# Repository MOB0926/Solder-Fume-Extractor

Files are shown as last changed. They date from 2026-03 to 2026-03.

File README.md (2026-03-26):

# Solder-Fume-Extractor

# Why?

- I made this project because I needed a fan extarctor in general and thought it would be fun to just make one as a project for Blueprint, in my effrot to gain experience in engeneering and design.

# What?

- This project is my attempt at making a custom fume extractor using a 120mm pc fan and a custom PCB.
   
- In order to not waste a full MCU on just a fan I opted to add a few features and make this fan feature a rotary encoder, OLED display, and GPIO pins for working on projects.
        
- The fan and PCB are housed in a custom 3D-Printed case using some pc fan mounting screws
       
- My original goal with the design was to make it a economic as possible, but with the nesscesity of a custom PCB I opted instead to focus my main goal on hand-soldering the PCB, which is something I have been wanting to learn. 
        
# Case
       
- The design began with the case, which i brainstormed untill i developed a general idea in my head.
   
- Once i had a general idea I began taking measurements and designing every piece in Onshape.
   
- I started with the main body, keeping in mind space and acces to the PCB and a way to mount the fan.
    

   
- I whent with a panel at the bottom, and slots on the sides which would hold the post that supported the fan.
   

         

         
- After I was done with the base, I needed a way to mount the fan and add a filter to stop myself from touching the blades.
           
- I decided on a casing that would wrap around the fan and allow me to mount it to the posts, and a custom honey-comb filter
         

         

           
- Finally I inserted all my parts into an assembly where I put everything together
          

      
# PCB

- I made the case first in order to figure out the dimmensions of the PCB I would be able to include.
   
- My original idea was to use an rp2040 as I have experience with it and a very over complicated adjustable boost converter to power the fan, but it was too much for me and I was unable to verify it would work before finishing the project, so I completely restructured my PCB in a V2
     
- V2: This version is much more simple and includes all hand-solder friendly components in order to acomplish my goal. I opted for an ESP32 module and a basic 5 to 12 volt boost converter.
   

           

             

        
# Firmware
         
- This design does not require any firmare to work because of how the PCB works but you can digitally disable the fan through a mosfet (using IO6 on the MCU). I made google Gemini write me a quick c++ script for it which is placed in the code.txt file
       
- This board can use other languages like CircuitPython using the (ESP32-C3-Lyra V2.0 by Espressif) release as it uses the same MCU so it should work fine. But you can use whatever suits your project.

# Cost

- PCB: $2.10 (plus shipping)
- PCB Components: $19.19 (plus shipping)
- PC Fan: $10-$30 (or free if you have a spare one)
- PC Fan Mounting Screws: $5 (or free if you have a PC with spares)
- 3D-Printing Fillament: (unknown yet)

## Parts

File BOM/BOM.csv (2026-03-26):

Component | Price | Shipping | Total | Retailer
120mm Fan | $0.00 | $0.00 | $0.00 | Owned
PCB | $2.10 | $3.12 | $5.22 | JLCPCB
PCB Components | $19.19 | $9.95 | $29.14 | LCSC
3D-Printer Filament | $0.00 | $0.00 | $0.00 | Owned
Total | $21.29 | $13.07 | $34.36

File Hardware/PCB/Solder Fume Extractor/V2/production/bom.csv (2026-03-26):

Designator | Footprint | Quantity | Value | LCSC Part #
C1, C3, C4 | 1206 | 3 | 1uF
C10, C2 | 1206 | 2 | 10uF
C5, C6 | 1206 | 2 | 22uF
C7, C8, C9 | 1206 | 3 | 100nF
D1 | 1206 | 1 | LED
D2 | D_SOD-123 | 1 | 1N4148W
J1 | USB_C_Receptacle_HRO_TYPE-C-31-M-12 | 1 | USB_C_Receptacle_USB2.0_14P
J3 | PinHeader_1x03_P2.54mm_Vertical | 1 | Conn_01x03
J4, J5 | PinHeader_1x07_P2.54mm_Vertical | 2 | Conn_01x07
L1 | IND-SMD_L5.7-W5.2 | 1 | 22uH
Q1 | SOT-23-3_L2.9-W1.3-P1.90-LS2.4-BR | 1 | AO3400A | C20917
R1 | 1206 | 1 | 100
R10, R2, R9 | 1206 | 3 | 10k
R18, R5, R6 | 1206 | 3 | 220
R3, R4 | 1206 | 2 | 5.1k
R7 | 1206 | 1 | 910k
R8 | 1206 | 1 | 47k
SW1 | SW-TH_EC11XXXXXXXX | 1 | EC11E09244BS | C470742
SW2 | KEY-SMD_L4.0-W3.0-LS4.9-1 | 1 | HX 3X4X2-2P-1.6N TACTILE SWITCH | C49234124
U1 | ESP32-C3-WROOM-02 | 1 | ESP32-C3-WROOM-02
U2 | SOT-23-3_L2.9-W1.6-P1.90-LS2.8-BR | 1 | MCP1700T-3302E/TT | C39051
U3 | SOT-23-6 | 1 | MT3608
U4 | SOT-23-6 | 1 | USBLC6-2SC6
U5 | OLED-TH_L27.8-W27.2-P2.54_C9900033791 | 1 | HS96L03W2C03 | C5248080

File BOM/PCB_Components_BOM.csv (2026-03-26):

Component LCSC# | Qty | Price
C5248080 | 1 | $2.16
C2907507 | 100 | $0.26
C52210003 | 100 | $0.18
C2933642 | 100 | $0.31
C2907509 | 100 | $0.24
C2907423 | 100 | $0.26
C2907369 | 100 | $0.33
C1945 | 10 | $0.18
C7419438 | 10 | $0.44
C28322 | 10 | $0.23
C9807 | 10 | $0.34
C7461351 | 5 | $0.70
C28310439 | 50 | $0.53
C917030 | 100 | $0.57
C700953 | 20 | $0.59
C7519 | 5 | $0.69
C49234124 | 50 | $0.89
C20882995 | 1 | $3.71
C84817 | 10 | $0.79
C84817 | 1 | $3.07
C165948 | 5 | $0.84
C39051 | 5 | $1.88
Total |  | $19.19

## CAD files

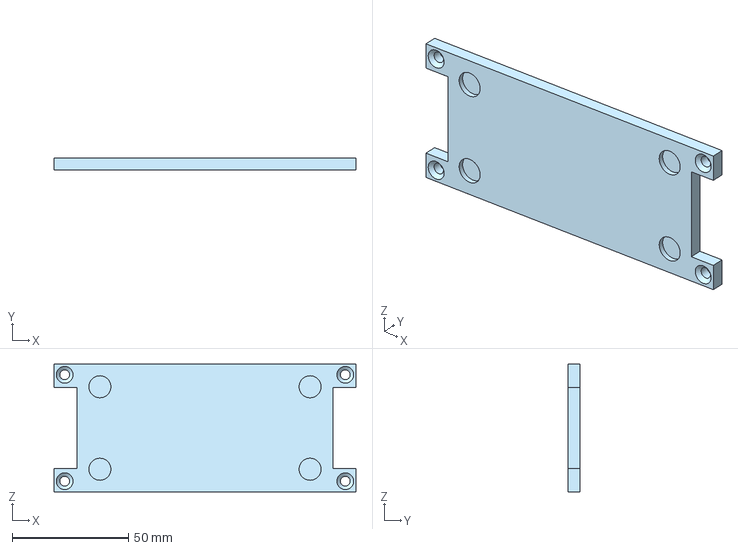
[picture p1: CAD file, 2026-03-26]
Hardware/Case/Parts/Bottom Panel.step
130.0 x 5.00 x 55.0 mm

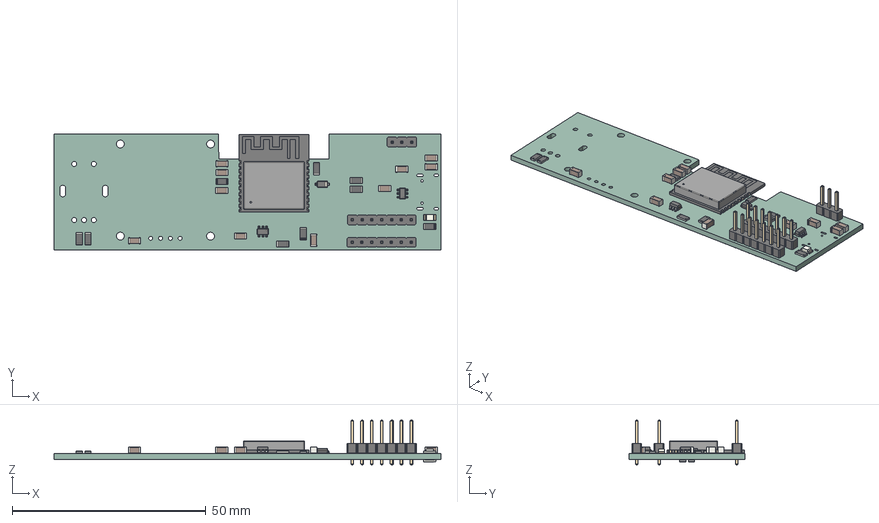
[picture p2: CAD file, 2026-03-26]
Hardware/PCB/Solder Fume Extractor/V2/Solder Fume Extractor - V2.step
100.0 x 30.0 x 11.5 mm
C_1206_3216Metric x 10
R_1206_3216Metric x 11
PinHeader_1x07_P2.54mm_Vertical x 2
PinHeader_1x03_P2.54mm_Vertical
SOT-23-6 x 2
ESP32-C3-WROOM-02
D_SOD-123
LED_1206_3216Metric
Solder Fume Extractor - V2_PCB

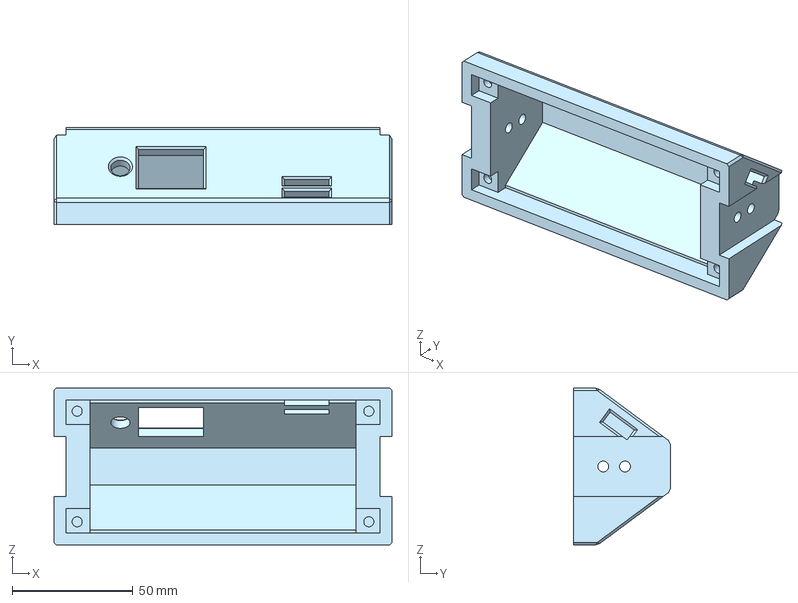
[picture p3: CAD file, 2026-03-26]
Hardware/Case/Parts/Body.step
140.0 x 40.0 x 65.0 mm

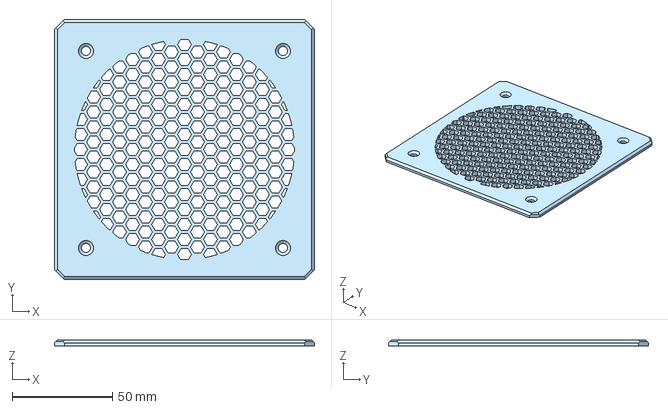
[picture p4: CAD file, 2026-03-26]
Hardware/Case/Parts/Fan Filter.step
130.0 x 130.0 x 3.00 mm

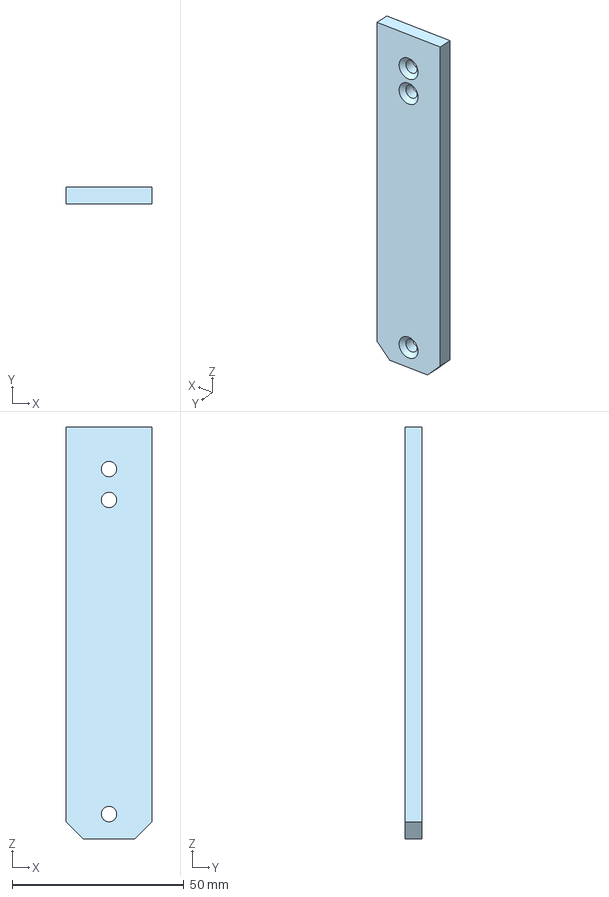
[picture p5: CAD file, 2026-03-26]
Hardware/Case/Parts/Post.step
25.0 x 5.00 x 120.0 mm

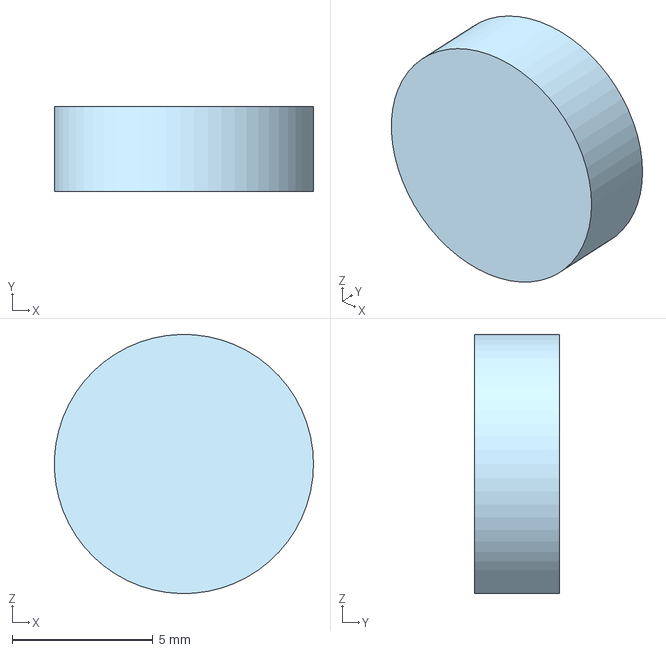
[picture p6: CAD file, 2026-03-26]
Hardware/Case/Parts/Feet.step
9.19 x 3.00 x 9.20 mm

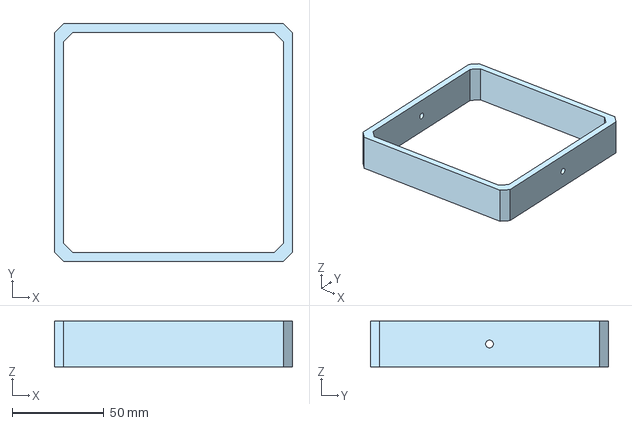
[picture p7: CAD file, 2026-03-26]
Hardware/Case/Parts/Fan Casing.step
130.0 x 130.0 x 25.0 mm

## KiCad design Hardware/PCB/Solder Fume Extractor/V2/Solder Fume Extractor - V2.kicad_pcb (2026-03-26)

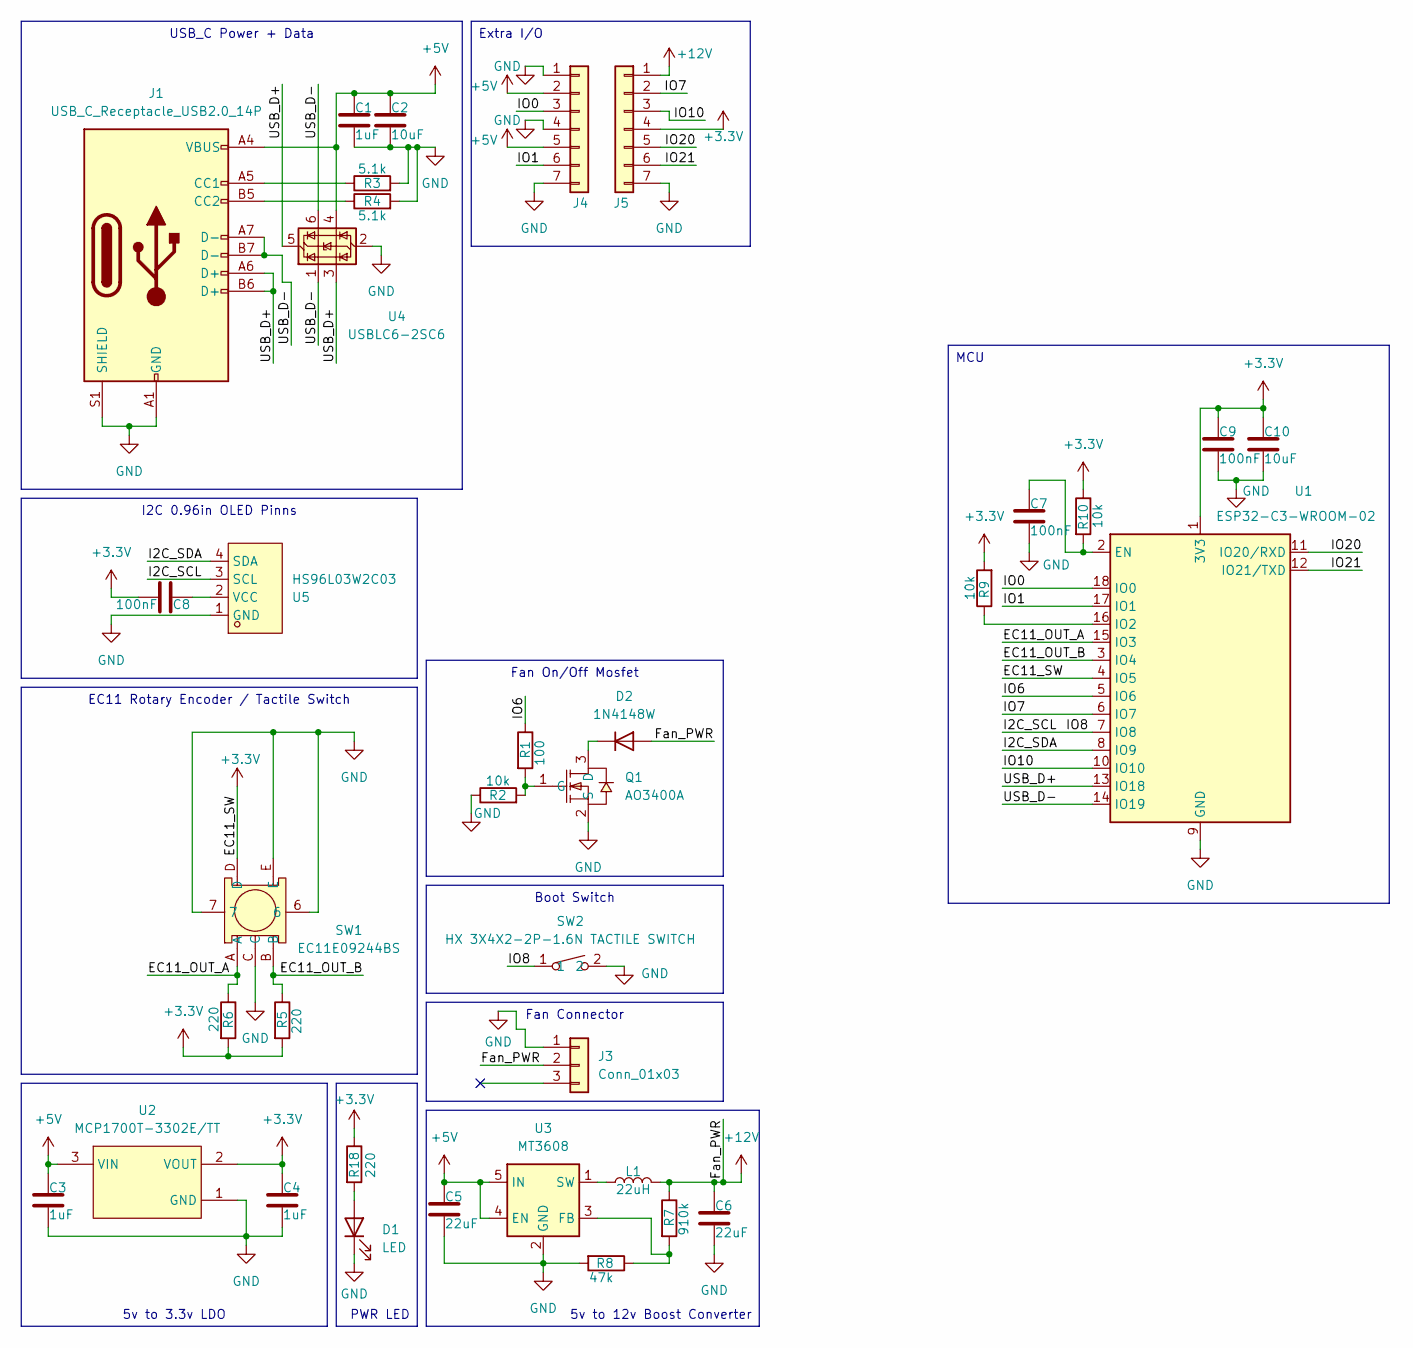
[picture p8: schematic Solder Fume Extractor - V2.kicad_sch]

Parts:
C1, C3, C4: 1uF; C_1206_3216Metric_Pad1.33x1.80mm_HandSolder
C2, C10: 10uF; C_1206_3216Metric_Pad1.33x1.80mm_HandSolder
C5, C6: 22uF; C_1206_3216Metric_Pad1.33x1.80mm_HandSolder
C7, C8, C9: 100nF; C_1206_3216Metric_Pad1.33x1.80mm_HandSolder
D1: LED; LED_1206_3216Metric_Pad1.42x1.75mm_HandSolder
D2: 1N4148W; D_SOD-123
J1: USB_C_Receptacle_USB2.0_14P; USB_C_Receptacle_HRO_TYPE-C-31-M-12
J3: Conn_01x03; PinHeader_1x03_P2.54mm_Vertical
J4, J5: Conn_01x07; PinHeader_1x07_P2.54mm_Vertical
L1: 22uH; IND-SMD_L5.7-W5.2
Q1: AO3400A; SOT-23-3_L2.9-W1.3-P1.90-LS2.4-BR; LCSC Part C20917
R1: 100; R_1206_3216Metric_Pad1.30x1.75mm_HandSolder
R2, R9, R10: 10k; R_1206_3216Metric_Pad1.30x1.75mm_HandSolder
R3, R4: 5.1k; R_1206_3216Metric_Pad1.30x1.75mm_HandSolder
R5, R6, R18: 220; R_1206_3216Metric_Pad1.30x1.75mm_HandSolder
R7: 910k; R_1206_3216Metric_Pad1.30x1.75mm_HandSolder
R8: 47k; R_1206_3216Metric_Pad1.30x1.75mm_HandSolder
SW1: EC11E09244BS; SW-TH_EC11XXXXXXXX; LCSC Part C470742
SW2: HX 3X4X2-2P-1.6N TACTILE SWITCH; KEY-SMD_L4.0-W3.0-LS4.9-1; LCSC Part C49234124
U1: ESP32-C3-WROOM-02
U2: MCP1700T-3302E/TT; SOT-23-3_L2.9-W1.6-P1.90-LS2.8-BR; LCSC Part C39051
U3: MT3608; SOT-23-6
U4: USBLC6-2SC6; SOT-23-6
U5: HS96L03W2C03; OLED-TH_L27.8-W27.2-P2.54_C9900033791; LCSC Part C5248080

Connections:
+3.3V: C4.1, C8.1, C9.1, C10.1, J5.4, R5.2, R6.2, R9.2, R10.1, R18.1, SW1.D, U1.1 (3V3), U1.4 (IO5), U2.2 (VOUT)
+5V: C1.1, C2.1, C3.1, C5.1, J1.A4 (VBUS), J1.A9 (VBUS), J1.B4 (VBUS), J1.B9 (VBUS), J4.2, J4.5, U2.3 (VIN), U3.4 (EN), U3.5 (IN), U4.4 (I/O2)
+12V: C6.1, D2.2 (A), J3.2, J5.1, L1.2, R7.1
/EC11_OUT_A: R6.1, SW1.A, U1.15 (IO3)
/EC11_OUT_B: R5.1, SW1.B, U1.3 (IO4)
/I2C_SCL: SW2.1, U1.7 (IO8), U5.3 (SCL)
/I2C_SDA: U1.8 (IO9), U5.4 (SDA)
/IO0: J4.3, U1.18 (IO0)
/IO1: J4.6, U1.17 (IO1)
/IO6: R1.1, U1.5 (IO6)
/IO7: J5.2, U1.6 (IO7)
/IO10: J5.3, U1.10 (IO10)
/IO20: J5.5, U1.11 (IO20/RXD)
/IO21: J5.6, U1.12 (IO21/TXD)
/USB_D+: J1.A6 (D+), J1.B6 (D+), U1.13 (IO18), U4.3 (I/O2), U4.5 (VBUS)
/USB_D-: J1.A7 (D-), J1.B7 (D-), U1.14 (IO19), U4.1 (I/O1), U4.6 (I/O1)
GND: C1.2, C2.2, C3.2, C4.2, C5.2, C6.2, C7.2, C9.2, C10.2, D1.1 (K), J1.A1 (GND), J1.A12 (GND), J1.B1 (GND), J1.B12 (GND), J1.S1 (SHIELD), J3.1, J4.1, J4.4, J4.7, J5.7, Q1.2 (S), R2.1, R3.2, R4.2, R8.2, SW1.6, SW1.7, SW1.C, SW1.E, SW2.2, U1.9 (GND), U1.19 (GND), U2.1 (GND), U3.2 (GND), U4.2 (GND), U5.1 (GND)
unnamed: D1.2 (A), R18.2
unnamed: D2.1 (K), Q1.3 (D)
unnamed: J1.A5 (CC1), R3.1
unnamed: J1.B5 (CC2), R4.1
unnamed: Q1.1 (G), R1.2, R2.2
unnamed: C7.1, R10.2, U1.2 (EN)
unnamed: R9.1, U1.16 (IO2)
unnamed: R7.2, R8.1, U3.3 (FB)
unnamed: L1.1, U3.1 (SW)
unnamed: C8.2, U5.2 (VCC)

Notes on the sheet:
I2C 0.96in OLED Pinns
PWR LED
5v to 3.3v LDO
MCU
5v to 12v Boost Converter
Boot Switch
Extra I/O
USB_C Power + Data
Fan Connector
Fan On/Off Mosfet
EC11 Rotary Encoder / Tactile Switch

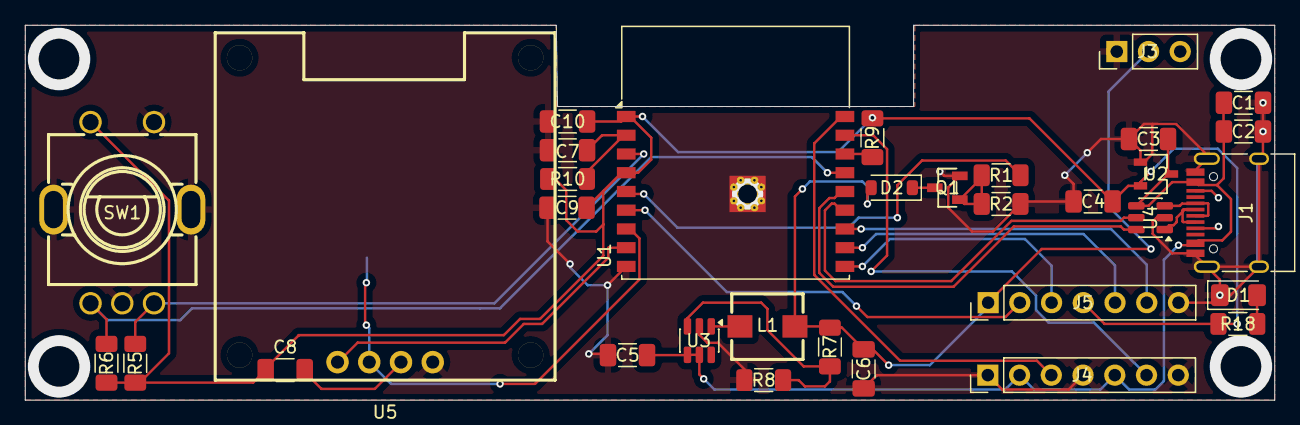
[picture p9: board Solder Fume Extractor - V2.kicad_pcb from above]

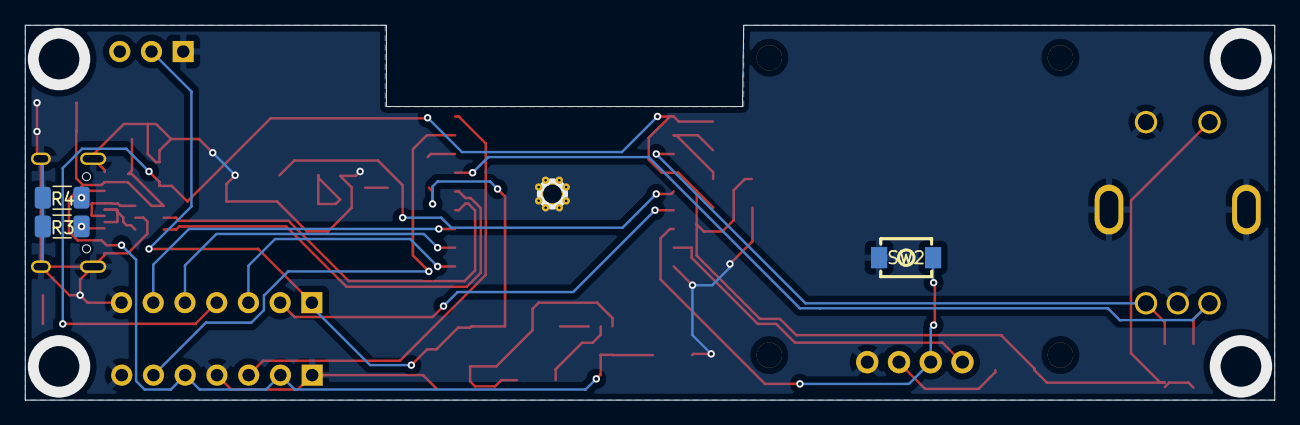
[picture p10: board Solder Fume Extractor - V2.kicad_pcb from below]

Board: 2 copper layers, 100.0 x 30.0 mm, 36 parts (3 on the bottom side), 27 nets.

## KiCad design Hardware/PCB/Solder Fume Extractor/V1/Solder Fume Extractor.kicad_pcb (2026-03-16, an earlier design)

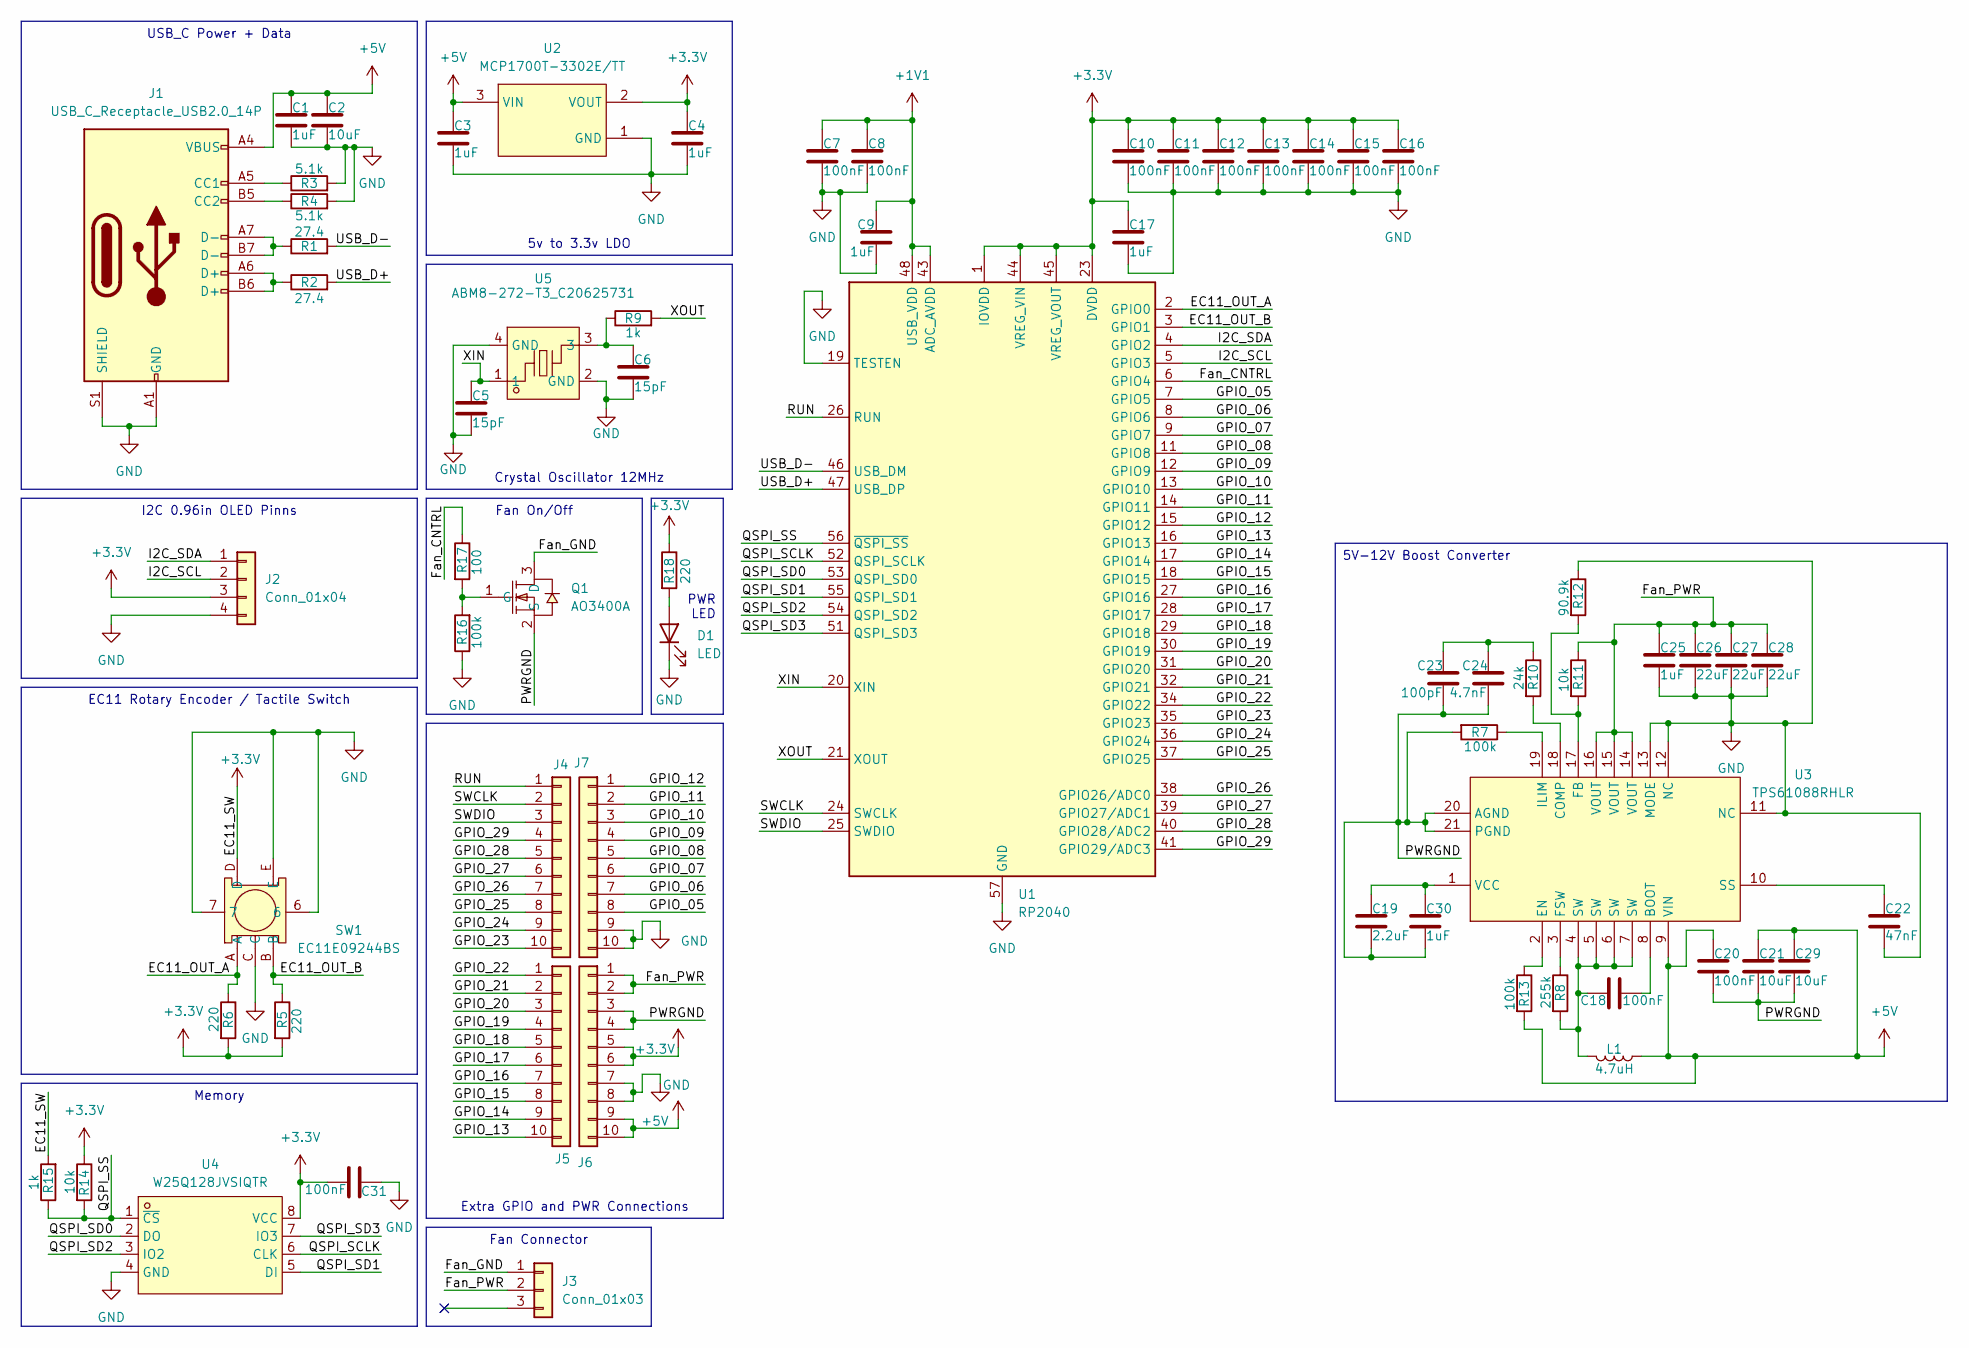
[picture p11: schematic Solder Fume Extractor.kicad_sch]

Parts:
C1, C3, C4, C9, C17, C25, C30: 1uF; C_0603_1608Metric
C2: 10uF; C_0603_1608Metric
C5, C6: 15pF; C_0603_1608Metric
C7, C8, C10, C11, C12, C13, C14, C15, C16, C18, C20, C31: 100nF; C_0603_1608Metric
C19: 2.2uF; C_0603_1608Metric
C21, C29: 10uF; C_1210_3225Metric
C22: 47nF; C_0603_1608Metric
C23: 100pF; C_0603_1608Metric
C24: 4.7nF; C_0603_1608Metric
C26, C27, C28: 22uF; C_1210_3225Metric
D1: LED; LED_0603_1608Metric
J1: USB_C_Receptacle_USB2.0_14P; USB_C_Receptacle_HRO_TYPE-C-31-M-12
J2: Conn_01x04; PinHeader_1x04_P2.54mm_Vertical
J3: Conn_01x03; PinHeader_1x03_P2.54mm_Vertical
J4, J5, J6, J7: Conn_01x10; PinHeader_1x10_P2.54mm_Vertical
L1: 4.7uH; L_Taiyo-Yuden_NR-60xx_HandSoldering
Q1: AO3400A; SOT-23-3_L2.9-W1.3-P1.90-LS2.4-BR; LCSC Part C20917
R1, R2: 27.4; R_0603_1608Metric
R3, R4: 5.1k; R_0603_1608Metric
R5, R6, R18: 220; R_0603_1608Metric
R7: 100k; C_0603_1608Metric
R8: 255k; R_0603_1608Metric
R9, R15: 1k; R_0603_1608Metric
R10: 24k; R_0603_1608Metric
R11, R14: 10k; R_0603_1608Metric
R12: 90.9k; R_0603_1608Metric
R13, R16: 100k; R_0603_1608Metric
R17: 100; R_0603_1608Metric
SW1: EC11E09244BS; SW-TH_EC11XXXXXXXX; LCSC Part C470742
U1: RP2040; QFN-56-1EP_7x7mm_P0.4mm_EP3.2x3.2mm
U2: MCP1700T-3302E/TT; SOT-23-3_L2.9-W1.6-P1.90-LS2.8-BR; LCSC Part C39051
U3: TPS61088RHLR; VQFN-20_L4.6-W3.6-P0.50-BL; LCSC Part C87357
U4: W25Q128JVSIQTR; SOIC-8_L5.3-W5.3-P1.27-LS8.0-BL; LCSC Part C97521
U5: ABM8-272-T3_C20625731; CRYSTAL-SMD_4P-L3.2-W2.5-BL; LCSC Part C20625731

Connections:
+1V1: C7.1, C8.1, C9.1, U1.43 (ADC_AVDD), U1.48 (USB_VDD)
+3.3V: C4.1, C10.1, C11.1, C12.1, C13.1, C14.1, C15.1, C16.1, C17.1, C31.2, J2.3, J6.5, J6.6, R5.2, R6.2, R14.1, R15.2, R18.1, SW1.D, U1.1 (IOVDD), U1.10 (IOVDD), U1.22 (IOVDD), U1.23 (DVDD), U1.33 (IOVDD), U1.42 (IOVDD), U1.44 (VREG_VIN), U1.45 (VREG_VOUT), U1.49 (IOVDD), U1.50 (DVDD), U2.2 (VOUT), U4.8 (VCC)
+5V: C1.1, C2.1, C3.1, C20.1, C21.1, C29.1, J1.A4 (VBUS), J1.A9 (VBUS), J1.B4 (VBUS), J1.B9 (VBUS), J6.9, J6.10, L1.2, R13.2, U2.3 (VIN), U3.9 (VIN)
/EC11_OUT_A: R6.1, SW1.A, U1.2 (GPIO0)
/EC11_OUT_B: R5.1, SW1.B, U1.3 (GPIO1)
/Fan_CNTRL: R17.1, U1.6 (GPIO4)
/Fan_GND: J3.1, Q1.3 (D)
/Fan_PWR: C25.1, C26.1, C27.1, C28.1, J3.2, J6.1, J6.2, R11.1, U3.14 (VOUT), U3.15 (VOUT), U3.16 (VOUT)
/GPIO_05: J7.8, U1.7 (GPIO5)
/GPIO_06: J7.7, U1.8 (GPIO6)
/GPIO_07: J7.6, U1.9 (GPIO7)
/GPIO_08: J7.5, U1.11 (GPIO8)
/GPIO_09: J7.4, U1.12 (GPIO9)
/GPIO_10: J7.3, U1.13 (GPIO10)
/GPIO_11: J7.2, U1.14 (GPIO11)
/GPIO_12: J7.1, U1.15 (GPIO12)
/GPIO_13: J5.10, U1.16 (GPIO13)
/GPIO_14: J5.9, U1.17 (GPIO14)
/GPIO_15: J5.8, U1.18 (GPIO15)
/GPIO_16: J5.7, U1.27 (GPIO16)
/GPIO_17: J5.6, U1.28 (GPIO17)
/GPIO_18: J5.5, U1.29 (GPIO18)
/GPIO_19: J5.4, U1.30 (GPIO19)
/GPIO_20: J5.3, U1.31 (GPIO20)
/GPIO_21: J5.2, U1.32 (GPIO21)
/GPIO_22: J5.1, U1.34 (GPIO22)
/GPIO_23: J4.10, U1.35 (GPIO23)
/GPIO_24: J4.9, U1.36 (GPIO24)
/GPIO_25: J4.8, U1.37 (GPIO25)
/GPIO_26: J4.7, U1.38 (GPIO26/ADC0)
/GPIO_27: J4.6, U1.39 (GPIO27/ADC1)
/GPIO_28: J4.5, U1.40 (GPIO28/ADC2)
/GPIO_29: J4.4, U1.41 (GPIO29/ADC3)
/I2C_SCL: J2.2, U1.5 (GPIO3)
/I2C_SDA: J2.1, U1.4 (GPIO2)
/PWRGND: C19.2, C20.2, C21.2, C23.2, C24.2, C29.2, C30.2, J6.3, J6.4, Q1.2 (S), R7.2, U3.20 (AGND), U3.21 (PGND)
/QSPI_SCLK: U1.52 (QSPI_SCLK), U4.6 (CLK)
/QSPI_SD0: U1.53 (QSPI_SD0), U4.2 (DO)
/QSPI_SD1: U1.55 (QSPI_SD1), U4.5 (DI)
/QSPI_SD2: U1.54 (QSPI_SD2), U4.3 (IO2)
/QSPI_SD3: U1.51 (QSPI_SD3), U4.7 (IO3)
/QSPI_SS: R14.2, R15.1, U1.56 (~QSPI_SS), U4.1 (~CS)
/RUN: J4.1, U1.26 (RUN)
/SWCLK: J4.2, U1.24 (SWCLK)
/SWDIO: J4.3, U1.25 (SWDIO)
/USB_D+: R2.2, U1.47 (USB_DP)
/USB_D-: R1.2, U1.46 (USB_DM)
/XIN: C5.1, U1.20 (XIN), U5.1
/XOUT: R9.2, U1.21 (XOUT)
GND: C1.2, C2.2, C3.2, C4.2, C5.2, C6.2, C7.2, C8.2, C9.2, C10.2, C11.2, C12.2, C13.2, C14.2, C15.2, C16.2, C17.2, C22.2, C25.2, C26.2, C27.2, C28.2, C31.1, D1.1 (K), J1.A1 (GND), J1.A12 (GND), J1.B1 (GND), J1.B12 (GND), J1.S1 (SHIELD), J2.4, J6.7, J6.8, J7.9, J7.10, R3.2, R4.2, R12.1, R16.1, SW1.6, SW1.7, SW1.C, SW1.E, U1.19 (TESTEN), U1.57 (GND), U2.1 (GND), U3.11 (NC), U3.12 (NC), U3.13 (MODE), U4.4 (GND), U5.2 (GND), U5.4 (GND)
unnamed: C6.1, R9.1, U5.3
unnamed: C18.1, L1.1, R8.2, U3.4 (SW), U3.5 (SW), U3.6 (SW), U3.7 (SW)
unnamed: C23.1, C24.1, R10.1
unnamed: D1.2 (A), R18.2
unnamed: J1.A5 (CC1), R3.1
unnamed: J1.B5 (CC2), R4.1
unnamed: J1.A6 (D+), J1.B6 (D+), R2.1
unnamed: J1.A7 (D-), J1.B7 (D-), R1.1
unnamed: Q1.1 (G), R16.2, R17.2
unnamed: C18.2, U3.8 (BOOT)
unnamed: R10.2, U3.18 (COMP)
unnamed: R13.1, U3.2 (EN)
unnamed: R11.2, R12.2, U3.17 (FB)
unnamed: R8.1, U3.3 (FSW)
unnamed: R7.1, U3.19 (ILIM)
unnamed: C22.1, U3.10 (SS)
unnamed: C19.1, C30.1, U3.1 (VCC)

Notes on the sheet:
Extra GPIO and PWR Connections
Crystal Oscillator 12MHz
I2C 0.96in OLED Pinns
PWR LED
5v to 3.3v LDO
Memory
USB_C Power + Data
Fan Connector
5V-12V Boost Converter
Fan On/Off
EC11 Rotary Encoder / Tactile Switch

Board: 2 copper layers, 65 parts (0 on the bottom side), 67 nets, no tracks yet.

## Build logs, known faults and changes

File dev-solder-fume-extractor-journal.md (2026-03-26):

<!--
  This journal is auto generated by Hack Club Blueprint.
-->

# 3/14/2026 6 PM - Creating Case  

_Time spent: 5.0h_  

I have been quite busy with school and FRC so I really slowed down on this project but here is what I have done since I started

**Mid February - Early March - Progress**

Created the majority of the case


(Main body, with holes for mounting fan supports and placing PCB)
(Will modify to fit port holes for PCB)


(Posts to attach the main body to the fan)


(Bottom Panel to close the bottom of the main body, and has slots for rubber feet to stop it from sliding)

**What's Next**

1. I need to make a piece of plastic that will go around the fan and will allow me to screw it to the posts and have a slot for the carbon filter.

2. I need to finish my PCB so I can make sure my case fits properly and I can submit my project.  

# 3/14/2026 7 PM - Creating PCB  

_Time spent: 5.0h_  

Yes second post today. I finally have gotten the motivation to Journal the little progress I have made in this busy time.

**PCB**





- I had originally planned to use an RP-2040 to control an adjustable boost converter from a range of 5v to 12v, and use the EC-11 to adjust the voltage, and display the voltage or RPM on the OLED display.

- I made a lot of progress with this design but I had definitely over complicated the design / idea and had to complicate with AI for researching topics I do not understand so I do not really trust this design. 

- Additionally I have really been wanting to hand-solder my design so I have decided to restart 	with simpler and more hand solder friendly components.

(I hope this Journal makes sense, I had earlier written a very nicely-worded one but my tab reloaded and I had to rewrite this from memory :|   )  

# 3/15/2026 2 AM - V2 of PCB Almost Done  

_Time spent: 7.0h_  

Since my last update I have basically reworked the whole PCB

I changed MCU to a ESP32-C3-WROOM-02 module, which would simplify my design and make it easier to solder.

Additionally I redesigned my 5 to 12 volt boost setup, to be much easier to solder and to ensure it would actually work. 

I have completely finished my Schematic and have since moved on to the PCB design.



I am still working on the PCB but I have a general layout and have began routing most nets



As you can see the new layout and design choices have allowed me much more room for placing components and soldering so this version is a million times better than the last.

I would love to keep working but its 2am and I have homework I have to complete tomorrow.  

# 3/15/2026 9 PM - Finished PCB  

_Time spent: 2.0h_  

Im done routing the PCB and have fixed all the DRC errors, so I'm basically done with my PCB.





I will now commit my work to my repo, and get started on the final details and the more aesthetic part of this project.

Additionally I am getting all of my parts added to my LCSC cart and trying my nest to get the most economic ones (within reason)  

# 3/18/2026 - CAD  

_Time spent: 5.0h_  

**CAD**

Today I finished the major parts of the CAD


(assembly of the design)


(grill so i don't accidentally touch the fan while it spins (also looks nice))


(casing going around the fan that connects it with the posts and body)

**Additional Notes**

I spent A LOT of time on this because I am new to a few features that this project required 

This is my second assembly (That I fully completed) so far so that took a while. Additionally getting that pattern on the grill was an absolute pain due to me not fully understanding the Fill Pattern feature script an trying a few different methods just to come back to the beginning.

I still have to add the holes for the PCB I/O so its not fully done but almost

**Rant on why this took so long**

So basically the Fill Pattern tool is a feature script and not a fully integrated tool (its been out for a while so IDK why not yet) so its not exactly perfect. I originally tried to make the pattern and set its boundary as the circle I wanted the shape in. Apparently Fill Pattern does not like this so it WILL NOT WORK. After like an hour of trying things and watching videos I realized this was true by changing the boundary to the square which did work, but its not what I wanted (Side note if its still not working change the boundary to the backside of the object you are trying to use as your limit, IDK  why or how but this fixes it) This stress and towards the end anger lead to me just trying to do it manually (adding the hexagons one by one) which just wasted a few hours (it was a Sunday and I was watching YT on my second monitor, so wasted time but I was going to watch YT anyways so not really). Today at work (Wednesdays I have an internship instead of school) I zoned out during a meeting and came back to this topic in my head, where I realized that I could have just used Fill Pattern to create my pattern on the grill as a whole and then sketch the circle I wanted and another square around it and extrude that backwards to fill the hexagons that were outside of the circle. 

I kept messing up the hole spacing for the fan mounting holes. I had to download a fan design so I could finish my assembly but I downloaded two and they just were not the right sizes compared to the measurements of my reference fan I am using so I had to modify the fan I used and keep adjusting the spacing of the holes on the grill and fan which was a pain to keep constantly doing but I got it done in the end which is the part that matters

**TLDR**

Wasted a few hours instead of IDK thinking for a sec  

# 3/25/2026 - Submiting  

_Time spent: 5.0h_  

**Done!!!***
I know its a bit late in blueprint but I'm ready to submit. I have my design ready and my repo complete. Sadly im not sure if I will be able to ship (or if my design will be accepted due to how late I am) but ill give it a shot anyways.



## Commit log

2026-03-16 PCB Complete
    The PCB Schematic and Design is complete. Revision will be made to the aesthetic (Adding silkscreen and labeling parts)
    [Solder Fume Extractor - V2.kicad_pcb, Solder Fume Extractor - V2.kicad_sch, Solder Fume Extractor.kicad_pcb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]
2026-03-26 README
    Expanded the README to include project motivation, design details, PCB information, firmware notes, and cost breakdown.
2026-03-26 Design Done
    [Body.step, Bottom Panel.step, Fan Casing.step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]
2026-03-26 Now design done
    [BOM.csv, PCB_Components_BOM.csv, Solder Fume Extractor - V2.kicad_pcb]
